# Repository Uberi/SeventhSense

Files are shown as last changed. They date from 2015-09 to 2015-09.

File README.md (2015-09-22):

SeventhSense
============
SeventhSense is a simple armband that uses targeted vibrations to give the wearer the ability to sense the direction and magnitude of magnetic fields.

This repository contains all the source files needed to build one of these devices, includind all the component datasheets.

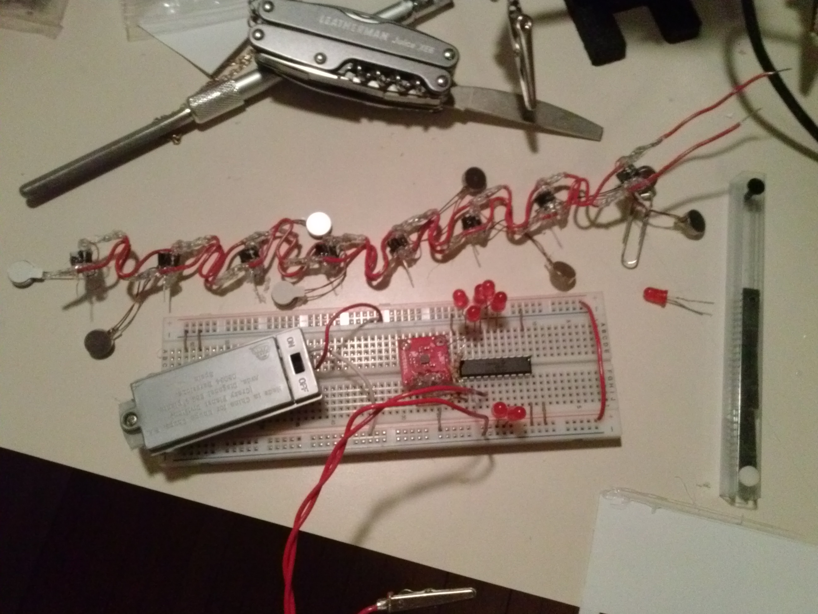
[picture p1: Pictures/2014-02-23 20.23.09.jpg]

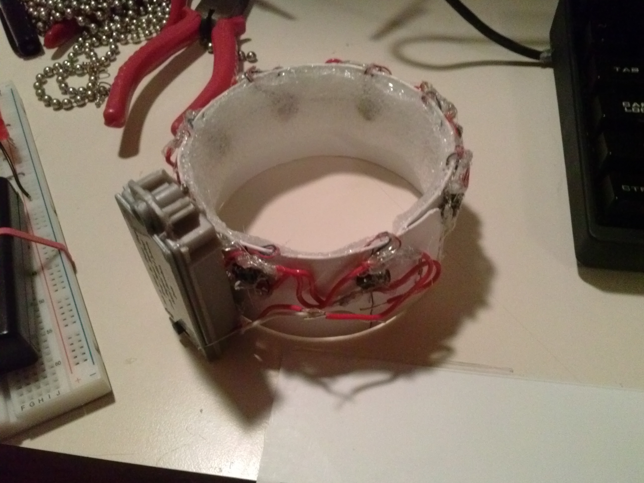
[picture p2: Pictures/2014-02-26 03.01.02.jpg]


See the `Pictures/` directory for more images!

Details
-------

The armband has 8 vibration motors embedded at equally spaced intervals. It is also connected to a 3-axis magnetometer and a microcontroller.

Roughly every second, the microcontroller reads the ambient magnetic field using the magnetometer, and then vibrates one of the motors just long enough for the user to notice.

Over time, the user will develop the ability to unconsciously interpret the signals while wearing the device. Due to the Earth's magnetic field, this allows the user to be aware of the current compass bearing.

The vibration motors indicate the magnetic field as one of 8 possible values: North, Northeast, East, Southeast, South, Southwest, West, and Northwest.

Parts List
----------

| Part | Quantity | Purpose |
|---|---|---|
| Double AAA battery pack with switch | 1 | Provides power for all the electronics. |
| PIC18F14K22 microcontroller (20-pin DIP) | 1 | Controls the magnetometer and vibration motors. |
| HMC5883 magnetometer (breakout board) | 1 | Measures ambient magnetic fields. |
| 310-101 vibration motor | 8 | Subtly notifies the user. |
| IN4001 rectifier diode | 8 | Flyback diode to protect delicate  circuitry. |
| 2N4401 NPN transistor | 8 | High current microcontroller-actuated switch. |
| Resistor (3300 Ohms) | 2 | Pull-up resistor for I2C communication lines. |
| Plastic sheeting | 30cm*5cm | Base material for armband. | ;wip; measure this
| Insulated electrical wire | ~1m | Connecting components together. |
| Insulated electrical wire | ~1m | Connecting components together. |

See the [parts list](Parts List.html) for a detailed bill of materials.

Tools Needed
------------

| Part | Quantity |
|---|---|
| Soldering Iron + solder | 1 |
| Hot Glue Gun + hot glue | 1 |
| Scissors | 1 |
| Pliers | 1 |

Building
--------

Refer to the [Fritzing design file](Design.fzz) for detailed electronic schematics.

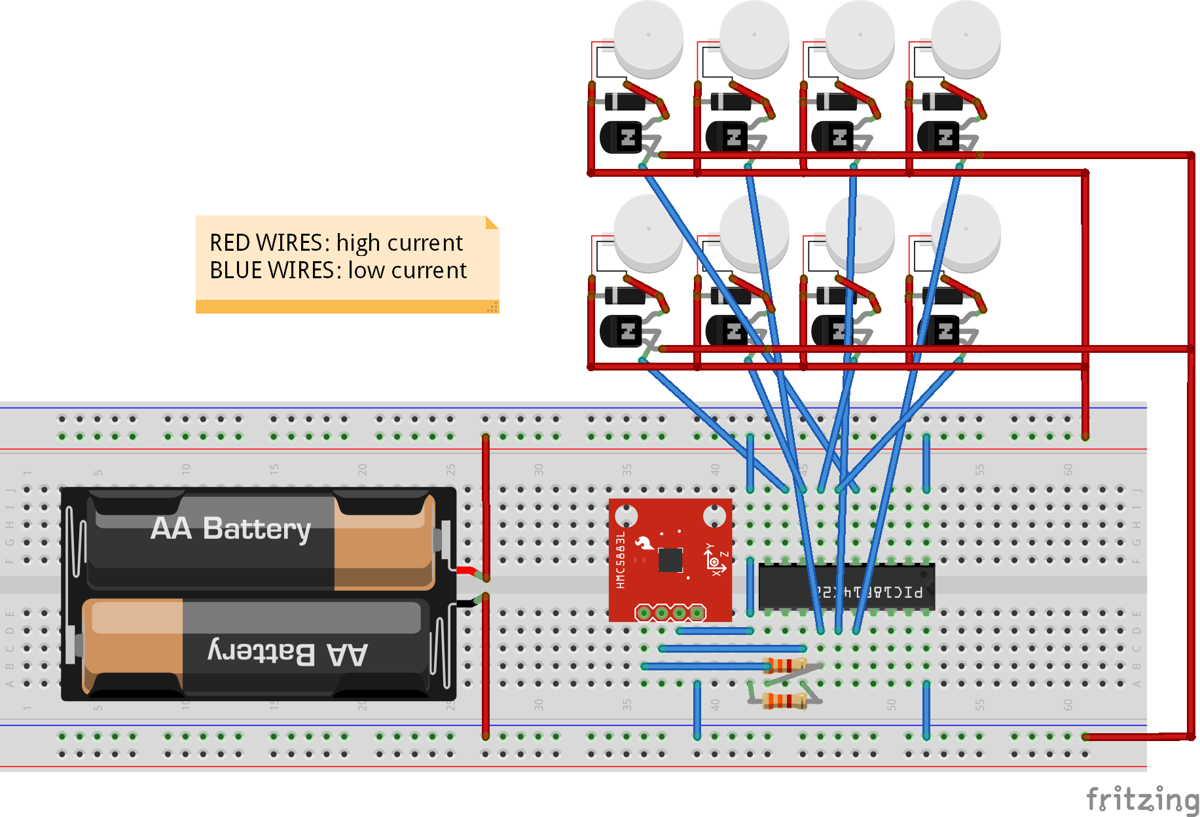
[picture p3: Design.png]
Schematic


1. Put together the vibration motor modules: each module has a transistor, a flyback diode, and a vibration motor.
    * First wrap the legs of the components together, then solder them together.
    * I personally smothered each module in hot glue as well so each one is individually waterproof.
    * Each module should have a power lead from the negative terminal of the flyback diode.
    * Each module should have a ground lead from the transistor emitter.
    * Each module should have a control lead from the transistor base.
    * This allows the main circuit to be simpler and makes the band have a lower profile.
2. Solder the power leads together and all the ground leads together for all the modules.
    * Make sure to separate them with wires that are at least 1/8 the outer circumference of the armband in length. This ensures that the resulting strip of modules will fit around the armband.
    * This is another good time to go crazy with the hot glue - make sure it's waterproof!
    * This is a good time to test the modules to make sure they all work.
3. Make an armband. Pad the inside with closed cell foam.
    * I used a stiff plastic that came from a set of window blinds. Some people may prefer fabric bands, but I find that they are not as durable.
    * Make sure the armband fits on the upper arm - use on the lower arm results in awkward placement when putting one's arms on a desk or table.
    * Make sure it is closed cell foam - otherwise the foam will not survive extended wear while wet. Using rubber supports is also effective but is not breathable and may irritate some people's skin.
4. Glue the strip of modules to the armband.
    * It is helpful to mark out the exact locations before gluing to ensure the modules are evenly aligned.
    * In my version, the transistor/diode of each module is on the outside of the band, and the vibration motor is fitted to the inside.
5. Build the controller circuit (the electronics excluding the transistors, diodes, and vibration motors) using the Fritzing design file.
    * Program the microcontroller using the 
    * The microcontroller has its pins bent outwards, and the rest of the circuit is built around it.
    * The microcontroller pins that lead to the motor modules are left free at this point.
    * The pictures make a good reference for my compact version.
    * The battery pack should have long enough wires that it can be adjusted in a suitable position on the armband later.
    * The magnetometer should be kept away from the motors, which contain magnets, and any high current wires, which are marked in red, since they produce non-negligible magnetic fields.
6. Connect the correct microcontroller pins to the motor modules.
    * Microcontroller pins are delicate, and it is a good idea to immediately smother freshly soldered solder joints in glue to improve structural properties.
    * Actually, this is a good time to just cover everything electronic in glue.
    * Leave the wires to the ICSP pins free and accessible from the outside - this allows for reprogramming the firmware afterwards.
7. Glue the controller unit onto the armband and wire the controller pins to the motor modules.
    * The best position seems to be right beside the battery pack, since it is close to the power leads.
    * It is a good idea to cover all the electronics in some material to make the armband look better.
    * Add more hot glue to make it fully waterproof.

Now the armband can be tested. When turned on, the motor corresponding to the direction the armband is facing will vibrate every few seconds.

License
-------

Copyright 2014-2015 Anthony Zhang (Uberi).

The designs created under this project are licensed under the [GNU Affero General Public License](http://www.gnu.org/licenses/agpl-3.0.html).

Basically, this means everyone is free to use, modify, and distribute the files, as long as these modifications are also licensed the same way.

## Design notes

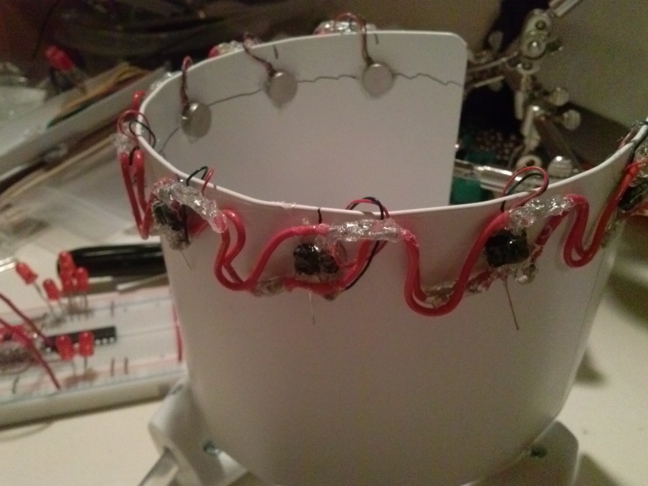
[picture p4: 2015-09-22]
Pictures/2014-02-23 21.24.51.jpg

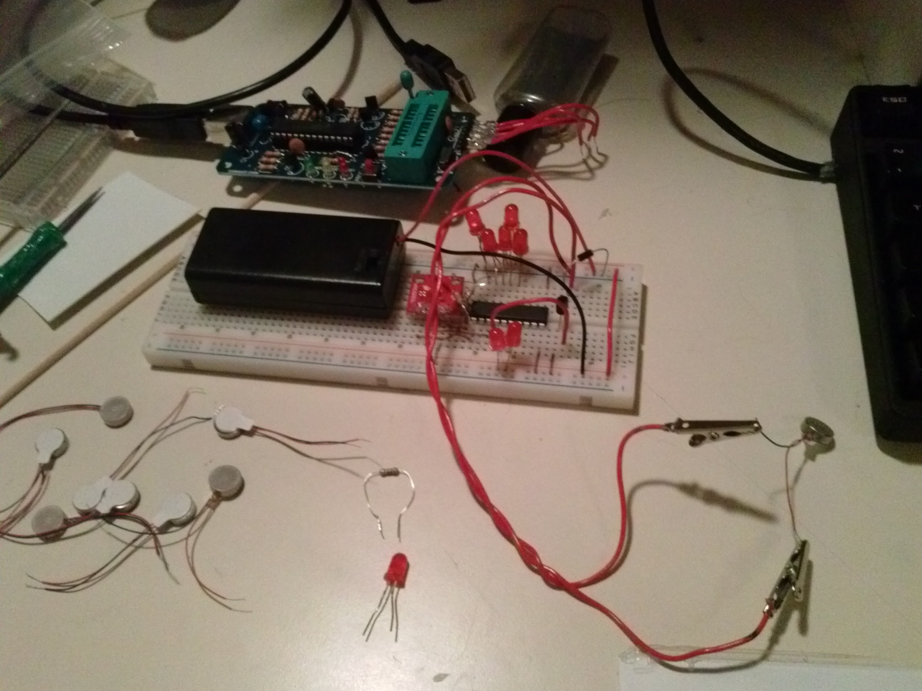
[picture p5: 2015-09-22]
Pictures/2014-02-22 00.40.16.jpg

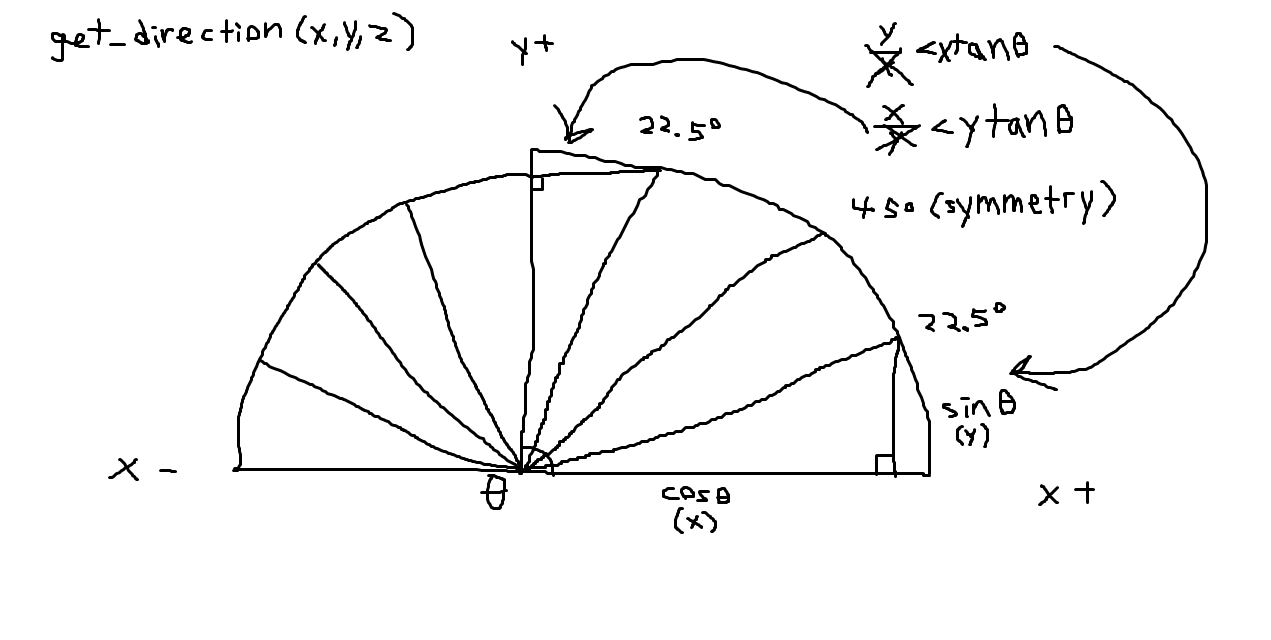
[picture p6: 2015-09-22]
I Grudgingly Respect Trigonometry.png

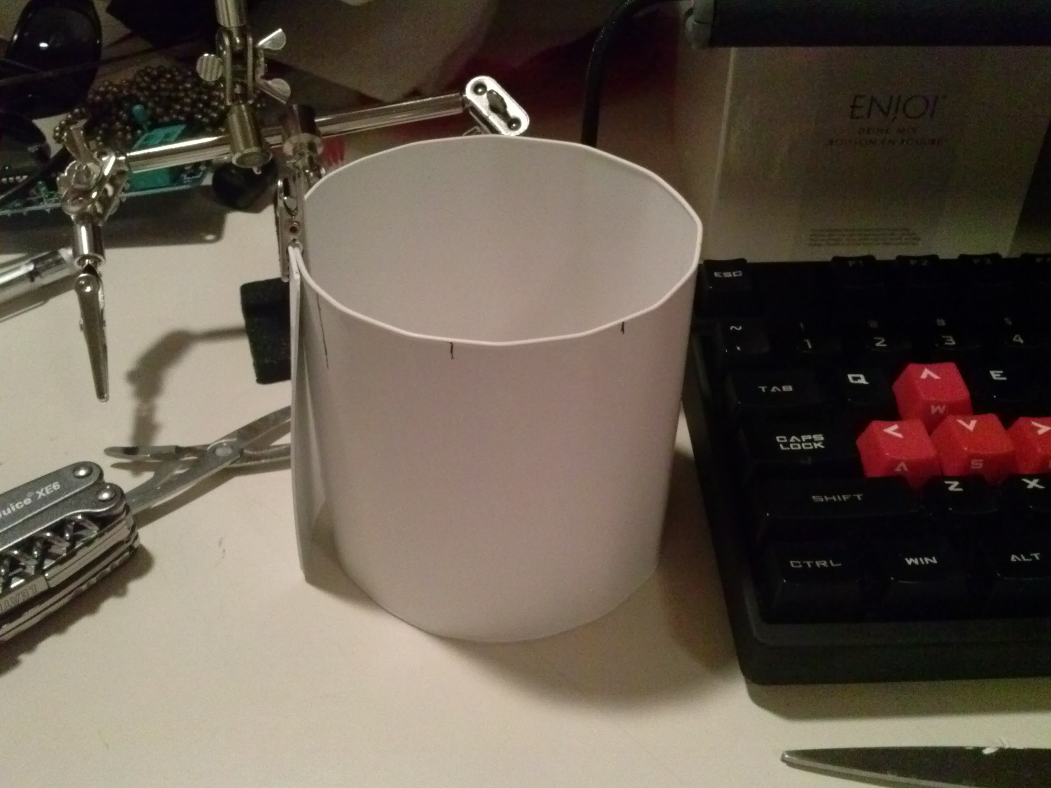
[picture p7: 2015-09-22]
Pictures/2014-02-23 20.43.08.jpg

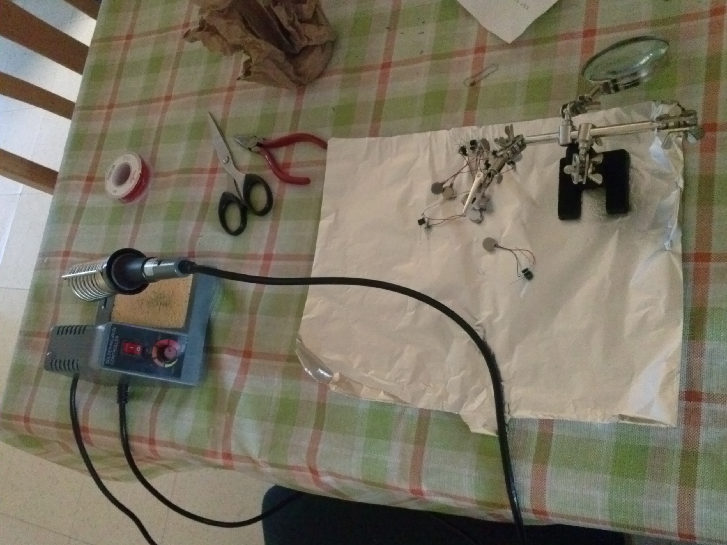
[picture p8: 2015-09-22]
Pictures/2014-02-22 16.46.31.jpg

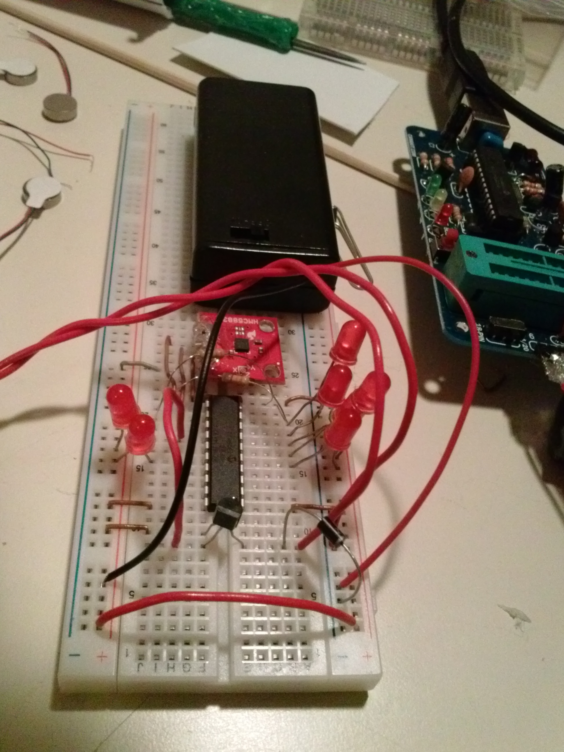
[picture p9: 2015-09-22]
Pictures/2014-02-22 00.41.09.jpg

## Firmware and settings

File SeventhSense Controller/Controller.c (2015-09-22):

/*
Anthony Zhang
Seventh Sense controller source code for PIC18F14K22 microcontrollers compiling with MikroC.
*/

/*
Functionality
-------------

1. Set up the microcontroller.
2. Start timer at 1 second interval:
    1. Initialize magnetometer if not already done.
    2. Take a reading from the magnetometer.
    3. Vibrate the right motor to notify the user.
*/

// motor pins are allocated based on physical location from left to right, top to bottom if the VDD side is facing upwards
#define MOTOR1 RC7_bit
#define MOTOR2 RC6_bit
#define MOTOR3 RC3_bit
#define MOTOR4 RC4_bit
#define MOTOR5 RC5_bit
#define MOTOR6 RC2_bit
#define MOTOR7 RC1_bit
#define MOTOR8 RC0_bit

#define MAGNETOMETER_WRITE 0x3C
#define MAGNETOMETER_READ 0x3D

#define MAGNETOMETER_OVERFLOW (-4096)

#define TRIG_SCALE (long)10000 // big number used to scale fixed point calculations
#define TAN_22_5 (long)4142 // TRIG_SCALE * tan(22.5 deg)

#define NORTH 1
#define NORTHEAST 2
#define EAST 3
#define SOUTHEAST 4
#define SOUTH 5
#define SOUTHWEST 6
#define WEST 7
#define NORTHWEST 8
#define NO_DIRECTION 0

int magnetic_x = 0;
int magnetic_y = 0;
int magnetic_z = 0;

void init_magnetometer() {
    TRISB = 0x00; // PORTB as output (required for I2C to work)
    PORTB = 0x00; // initialize PORTB to 0 for I2C

    I2C1_Init(100000); // start the I2C communication channel in standard mode (100 kbps)
    
    I2C1_Start();
    I2C1_Wr(MAGNETOMETER_WRITE); // write to magnetometer
    I2C1_Wr(0x00); // write to configuration A register
    I2C1_Wr(0b01110000); // average 8 samples
    I2C1_Stop();
}

//Timer1
//Prescaler 1:8; TMR1 Preload = 18661; Actual Interrupt Time : 1.5 s

//Generated by MikroC Timer Calculator
void init_timer1() {
    T1CON = 0x31;
    TMR1IF_bit = 0;
    TMR1H = 0x48;
    TMR1L = 0xE5;
    TMR1IE_bit = 1;
    INTCON = 0xC0;
}

void main() {
    CM1CON0 = CM2CON0 = 0b111; // comparator configuration
    ANSEL = ANSELH = 0; // use digital I/O
    IDLEN_bit = 1; // enable Idle mode when sleeping (timer1 only works in normal and idle mode)

    TRISC = 0x00; // PORTC as output
    MOTOR1 = MOTOR2 = MOTOR3 = MOTOR4 = MOTOR5 = MOTOR6 = 0; // reset port state

    init_timer1(); // configure timer1 to run every second

    asm sleep; // go into idle mode, later to be woken up by timer1
}

void get_magnetometer(int *x, int *y, int *z) {
    // tell the magnetometer to make a reading
    I2C1_Start();
    I2C1_Wr(MAGNETOMETER_WRITE); // write to magnetometer
    I2C1_Wr(0x02); // write to mode register
    I2C1_Wr(0b00000001); // single measurement mode
    I2C1_Stop();

    delay_ms(150); // wait for the magnetometer to make a reading

    // read the magnetometer reading
    I2C1_Start();
    I2C1_Wr(MAGNETOMETER_READ); // read from magnetometer
    *x = (I2C1_Rd(1) << 8) | I2C1_Rd(1);
    *z = (I2C1_Rd(1) << 8) | I2C1_Rd(1);
    *y = (I2C1_Rd(1) << 8) | I2C1_Rd(0); // we always NACK the last value to indicate that we are done reading
    I2C1_Stop();
}

void notify(int index) {
    switch (index) {
        case 1: MOTOR1 = 1; break;
        case 2: MOTOR2 = 1; break;
        case 3: MOTOR3 = 1; break;
        case 4: MOTOR4 = 1; break;
        case 5: MOTOR5 = 1; break;
        case 6: MOTOR6 = 1; break;
        case 7: MOTOR7 = 1; break;
        case 8: MOTOR8 = 1; break;
    }
    delay_ms(200);
    switch (index) {
        case 1: MOTOR1 = 0; break;
        case 2: MOTOR2 = 0; break;
        case 3: MOTOR3 = 0; break;
        case 4: MOTOR4 = 0; break;
        case 5: MOTOR5 = 0; break;
        case 6: MOTOR6 = 0; break;
        case 7: MOTOR7 = 0; break;
        case 8: MOTOR8 = 0; break;
    }
}

static long axis_x, axis_y;
char get_direction(int x, int y, int z) {
    // handle overflow values
    if (x == MAGNETOMETER_OVERFLOW
     || y == MAGNETOMETER_OVERFLOW
     || z == MAGNETOMETER_OVERFLOW)
        return NO_DIRECTION; // unknown index

    axis_x = (long)x;
    axis_y = (long)y;

    // handle edge cases
    if (axis_x == 0 && axis_y == 0) // no angle
        return NO_DIRECTION;
    if (axis_x == 0)
        return y < 0 ? SOUTH : NORTH;
    if (axis_y == 0)
        return x < 0 ? WEST : EAST;

    // handle the cases in between the extremes
    if (axis_x > 0 && axis_y > 0) { // first quadrant
        if (axis_y * TRIG_SCALE < axis_x * TAN_22_5) // angle less than 22.5 degrees
            return EAST;
        if (axis_x * TRIG_SCALE < axis_y * TAN_22_5) // angle more than 90 - 22.5 degrees
            return NORTH;
        return NORTHEAST;
    }
    if (axis_x < 0 && axis_y > 0) { // second quadrant
        if (axis_y * TRIG_SCALE < -axis_x * TAN_22_5) // angle less than 90 + 22.5 degrees
            return WEST;
        if (-axis_x * TRIG_SCALE < axis_y * TAN_22_5) // angle more than 180 - 22.5 degrees
            return NORTH;
        return NORTHWEST;
    }
    if (axis_x < 0 && axis_y < 0) { // third quadrant
        if (-axis_y * TRIG_SCALE < -axis_x * TAN_22_5) // angle less than 180 + 22.5 degrees
            return WEST;
        if (-axis_x * TRIG_SCALE < -axis_y * TAN_22_5) // angle more than 270 - 22.5 degrees
            return SOUTH;
        return SOUTHWEST;
    }
    // fourth quadrant
    if (-axis_y * TRIG_SCALE < axis_x * TAN_22_5) // angle less than 270 + 22.5 degrees
        return EAST;
    if (axis_x * TRIG_SCALE < -axis_y * TAN_22_5) // angle more than 360 - 22.5 degrees
        return SOUTH;
    return SOUTHEAST;
}

static char magnetometer_uninitialized = 1; // 1 if magnetometer is still yet to be initialized, 0 if already initialized
void interrupt(){
    if (TMR1IF_bit){
        // reset timer
        TMR1IF_bit = 0;
        TMR1H = 0x48;
        TMR1L = 0xE5;

        if (magnetometer_uninitialized) {
            init_magnetometer(); // configure magnetometer to take readings every second
            magnetometer_uninitialized = 0;
        }
        else {
            get_magnetometer(&magnetic_x, &magnetic_y, &magnetic_z);
            notify(get_direction(magnetic_x, magnetic_y, magnetic_z));
        }
    }
}

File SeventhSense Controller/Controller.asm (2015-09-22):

_init_magnetometer:

;Controller.c,49 :: 		void init_magnetometer() {
;Controller.c,50 :: 		TRISB = 0x00; // PORTB as output (required for I2C to work)
	CLRF        TRISB+0 
;Controller.c,51 :: 		PORTB = 0x00; // initialize PORTB to 0 for I2C
	CLRF        PORTB+0 
;Controller.c,53 :: 		I2C1_Init(100000); // start the I2C communication channel in standard mode (100 kbps)
	MOVLW       2
	MOVWF       SSPADD+0 
	CALL        _I2C1_Init+0, 0
;Controller.c,55 :: 		I2C1_Start();
	CALL        _I2C1_Start+0, 0
;Controller.c,56 :: 		I2C1_Wr(MAGNETOMETER_WRITE); // write to magnetometer
	MOVLW       60
	MOVWF       FARG_I2C1_Wr_data_+0 
	CALL        _I2C1_Wr+0, 0
;Controller.c,57 :: 		I2C1_Wr(0x00); // write to configuration A register
	CLRF        FARG_I2C1_Wr_data_+0 
	CALL        _I2C1_Wr+0, 0
;Controller.c,58 :: 		I2C1_Wr(0b01110000); // average 8 samples
	MOVLW       112
	MOVWF       FARG_I2C1_Wr_data_+0 
	CALL        _I2C1_Wr+0, 0
;Controller.c,59 :: 		I2C1_Stop();
	CALL        _I2C1_Stop+0, 0
;Controller.c,60 :: 		}
L_end_init_magnetometer:
	RETURN      0
; end of _init_magnetometer

_init_timer1:

;Controller.c,66 :: 		void init_timer1() {
;Controller.c,67 :: 		T1CON = 0x31;
	MOVLW       49
	MOVWF       T1CON+0 
;Controller.c,68 :: 		TMR1IF_bit = 0;
	BCF         TMR1IF_bit+0, BitPos(TMR1IF_bit+0) 
;Controller.c,69 :: 		TMR1H = 0x48;
	MOVLW       72
	MOVWF       TMR1H+0 
;Controller.c,70 :: 		TMR1L = 0xE5;
	MOVLW       229
	MOVWF       TMR1L+0 
;Controller.c,71 :: 		TMR1IE_bit = 1;
	BSF         TMR1IE_bit+0, BitPos(TMR1IE_bit+0) 
;Controller.c,72 :: 		INTCON = 0xC0;
	MOVLW       192
	MOVWF       INTCON+0 
;Controller.c,73 :: 		}
L_end_init_timer1:
	RETURN      0
; end of _init_timer1

_main:

;Controller.c,75 :: 		void main() {
;Controller.c,76 :: 		CM1CON0 = CM2CON0 = 0b111; // comparator configuration
	MOVLW       7
	MOVWF       CM2CON0+0 
	MOVF        CM2CON0+0, 0 
	MOVWF       CM1CON0+0 
;Controller.c,77 :: 		ANSEL = ANSELH = 0; // use digital I/O
	CLRF        ANSELH+0 
	CLRF        ANSEL+0 
;Controller.c,78 :: 		IDLEN_bit = 1; // enable Idle mode when sleeping (timer1 only works in normal and idle mode)
	BSF         IDLEN_bit+0, BitPos(IDLEN_bit+0) 
;Controller.c,80 :: 		TRISC = 0x00; // PORTC as output
	CLRF        TRISC+0 
;Controller.c,81 :: 		MOTOR1 = MOTOR2 = MOTOR3 = MOTOR4 = MOTOR5 = MOTOR6 = 0; // reset port state
	BCF         RC2_bit+0, BitPos(RC2_bit+0) 
	BTFSC       RC2_bit+0, BitPos(RC2_bit+0) 
	GOTO        L__main62
	BCF         RC5_bit+0, BitPos(RC5_bit+0) 
	GOTO        L__main63
L__main62:
	BSF         RC5_bit+0, BitPos(RC5_bit+0) 
L__main63:
	BTFSC       RC5_bit+0, BitPos(RC5_bit+0) 
	GOTO        L__main64
	BCF         RC4_bit+0, BitPos(RC4_bit+0) 
	GOTO        L__main65
L__main64:
	BSF         RC4_bit+0, BitPos(RC4_bit+0) 
L__main65:
	BTFSC       RC4_bit+0, BitPos(RC4_bit+0) 
	GOTO        L__main66
	BCF         RC3_bit+0, BitPos(RC3_bit+0) 
	GOTO        L__main67
L__main66:
	BSF         RC3_bit+0, BitPos(RC3_bit+0) 
L__main67:
	BTFSC       RC3_bit+0, BitPos(RC3_bit+0) 
	GOTO        L__main68
	BCF         RC6_bit+0, BitPos(RC6_bit+0) 
	GOTO        L__main69
L__main68:
	BSF         RC6_bit+0, BitPos(RC6_bit+0) 
L__main69:
	BTFSC       RC6_bit+0, BitPos(RC6_bit+0) 
	GOTO        L__main70
	BCF         RC7_bit+0, BitPos(RC7_bit+0) 
	GOTO        L__main71
L__main70:
	BSF         RC7_bit+0, BitPos(RC7_bit+0) 
L__main71:
;Controller.c,84 :: 		PORTC = 0xFF;
	MOVLW       255
	MOVWF       PORTC+0 
;Controller.c,86 :: 		asm sleep; // go into idle mode, later to be woken up by timer1
	SLEEP
;Controller.c,87 :: 		}
L_end_main:
	GOTO        $+0
; end of _main

_get_magnetometer:

;Controller.c,89 :: 		void get_magnetometer(int *x, int *y, int *z) {
;Controller.c,91 :: 		I2C1_Start();
	CALL        _I2C1_Start+0, 0
;Controller.c,92 :: 		I2C1_Wr(MAGNETOMETER_WRITE); // write to magnetometer
	MOVLW       60
	MOVWF       FARG_I2C1_Wr_data_+0 
	CALL        _I2C1_Wr+0, 0
;Controller.c,93 :: 		I2C1_Wr(0x02); // write to mode register
	MOVLW       2
	MOVWF       FARG_I2C1_Wr_data_+0 
	CALL        _I2C1_Wr+0, 0
;Controller.c,94 :: 		I2C1_Wr(0b00000001); // single measurement mode
	MOVLW       1
	MOVWF       FARG_I2C1_Wr_data_+0 
	CALL        _I2C1_Wr+0, 0
;Controller.c,95 :: 		I2C1_Stop();
	CALL        _I2C1_Stop+0, 0
;Controller.c,97 :: 		delay_ms(150); // wait for the magnetometer to make a reading
	MOVLW       49
	MOVWF       R12, 0
	MOVLW       178
	MOVWF       R13, 0
L_get_magnetometer0:
	DECFSZ      R13, 1, 1
	BRA         L_get_magnetometer0
	DECFSZ      R12, 1, 1
	BRA         L_get_magnetometer0
	NOP
;Controller.c,100 :: 		I2C1_Start();
	CALL        _I2C1_Start+0, 0
;Controller.c,101 :: 		I2C1_Wr(MAGNETOMETER_READ); // read from magnetometer
	MOVLW       61
	MOVWF       FARG_I2C1_Wr_data_+0 
	CALL        _I2C1_Wr+0, 0
;Controller.c,102 :: 		*x = (I2C1_Rd(1) << 8) | I2C1_Rd(1);
	MOVLW       1
	MOVWF       FARG_I2C1_Rd_ack+0 
	CALL        _I2C1_Rd+0, 0
	MOVF        R0, 0 
	MOVWF       FLOC__get_magnetometer+1 
	CLRF        FLOC__get_magnetometer+0 
	MOVLW       1
	MOVWF       FARG_I2C1_Rd_ack+0 
	CALL        _I2C1_Rd+0, 0
	MOVLW       0
	MOVWF       R1 
	MOVF        FLOC__get_magnetometer+0, 0 
	IORWF       R0, 1 
	MOVF        FLOC__get_magnetometer+1, 0 
	IORWF       R1, 1 
	MOVFF       FARG_get_magnetometer_x+0, FSR1
	MOVFF       FARG_get_magnetometer_x+1, FSR1H
	MOVF        R0, 0 
	MOVWF       POSTINC1+0 
	MOVF        R1, 0 
	MOVWF       POSTINC1+0 
;Controller.c,103 :: 		*z = (I2C1_Rd(1) << 8) | I2C1_Rd(1);
	MOVLW       1
	MOVWF       FARG_I2C1_Rd_ack+0 
	CALL        _I2C1_Rd+0, 0
	MOVF        R0, 0 
	MOVWF       FLOC__get_magnetometer+1 
	CLRF        FLOC__get_magnetometer+0 
	MOVLW       1
	MOVWF       FARG_I2C1_Rd_ack+0 
	CALL        _I2C1_Rd+0, 0
	MOVLW       0
	MOVWF       R1 
	MOVF        FLOC__get_magnetometer+0, 0 
	IORWF       R0, 1 
	MOVF        FLOC__get_magnetometer+1, 0 
	IORWF       R1, 1 
	MOVFF       FARG_get_magnetometer_z+0, FSR1
	MOVFF       FARG_get_magnetometer_z+1, FSR1H
	MOVF        R0, 0 
	MOVWF       POSTINC1+0 
	MOVF        R1, 0 
	MOVWF       POSTINC1+0 
;Controller.c,104 :: 		*y = (I2C1_Rd(1) << 8) | I2C1_Rd(0); // we always NACK the last value to indicate that we are done reading
	MOVLW       1
	MOVWF       FARG_I2C1_Rd_ack+0 
	CALL        _I2C1_Rd+0, 0
	MOVF        R0, 0 
	MOVWF       FLOC__get_magnetometer+1 
	CLRF        FLOC__get_magnetometer+0 
	CLRF        FARG_I2C1_Rd_ack+0 
	CALL        _I2C1_Rd+0, 0
	MOVLW       0
	MOVWF       R1 
	MOVF        FLOC__get_magnetometer+0, 0 
	IORWF       R0, 1 
	MOVF        FLOC__get_magnetometer+1, 0 
	IORWF       R1, 1 
	MOVFF       FARG_get_magnetometer_y+0, FSR1
	MOVFF       FARG_get_magnetometer_y+1, FSR1H
	MOVF        R0, 0 
	MOVWF       POSTINC1+0 
	MOVF        R1, 0 
	MOVWF       POSTINC1+0 
;Controller.c,105 :: 		I2C1_Stop();
	CALL        _I2C1_Stop+0, 0
;Controller.c,106 :: 		}
L_end_get_magnetometer:
	RETURN      0
; end of _get_magnetometer

_notify:
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
